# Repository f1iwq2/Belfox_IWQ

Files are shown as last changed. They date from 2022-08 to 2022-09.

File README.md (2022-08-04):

==============
Carte de remplacement pour portail coulissants BELFOX
pour pilotage de moteurs à courant continu - A base d'arduino nano

Documents dans le fichier pdf
Fichiers schéma Kicad
fichiers gerber dans le répertoire trace

Replacement control board for BELFOX sliding gates
Drive a DC moteur

Documents in pdf files
Kicad board schematics files
gerber files in trace directory

https://youtu.be/OYu1DCdmt-g

image::carte.jpg[]

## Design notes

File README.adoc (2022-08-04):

Carte BELFOX IWQ
================
Carte de remplacement pour portail coulissants BELFOX
pour pilotage de moteurs à courant continu - A base d'arduino nano

Documents dans le fichier pdf
Fichiers schéma Kicad
fichiers gerber dans le répertoire trace

Replacement control board for BELFOX sliding gates
Drive a DC moteur

Documents in pdf files
Kicad board schematics files
gerber files in trace directory

https://youtu.be/OYu1DCdmt-g

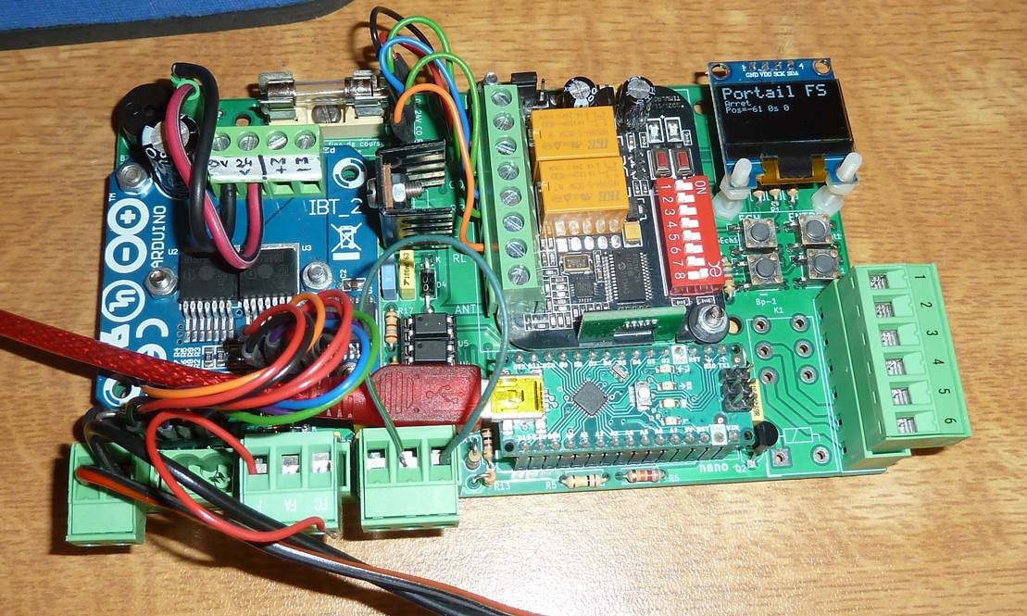
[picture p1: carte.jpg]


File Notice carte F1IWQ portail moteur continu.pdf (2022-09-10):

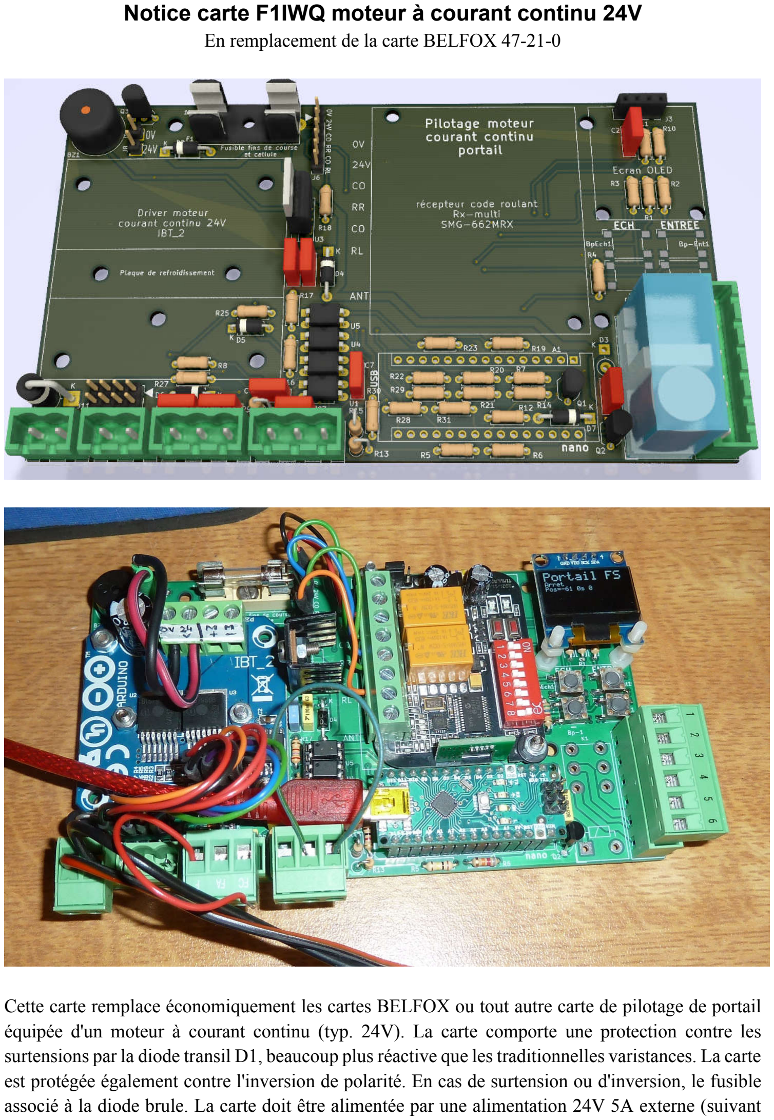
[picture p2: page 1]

### Notice carte F1IWQ moteur à courant continu 24V

En remplacement de la carte BELFOX 47-21-0

Cette carte remplace économiquement les cartes BELFOX ou tout autre carte de pilotage de portail équipée d'un moteur à courant continu (typ. 24V). La carte comporte une protection contre les surtensions par la diode transil D1, beaucoup plus réactive que les traditionnelles varistances. La carte est protégée également contre l'inversion de polarité. En cas de surtension ou d'inversion, le fusible associé à la diode brule. La carte doit être alimentée par une alimentation 24V 5A externe (suivant spécification du moteur). Par exemple la TXH 120-124 de tracopower (RS:706-6303). Prévoir un fusible en ligne de 5AF. Le module de pilotage du moteur est un IBT_2.

### Montage

Le boitier dans lequel la carte est montée n'autorise que les hauteurs de composants inférieures à 34 mm maximum. Le composant le plus haut est le relais (25mm)
Monter l'écran OLED sur le connecteur J3 et mettre deux vis / écrous M2,5 avec entretoise.
Monter le récepteur de télécommande avec des vis écrous M3 ; la platine du récepteur doit être surélevée d'un écrou. Mettre des rondelles nylon pour l'isolation au contact de la platine du récepteur. Insérer un fusible rapide 5x20 1A F sur le support.
Insérer l'Arduino NANO programmé à l'emplacement A1, prise USB vers la gauche sur 2 supports HE10 femelles 15 broches.

Le radiateur du module IBT_2 est à remplacer par deux barres aluminium 49x22mm ep 2mm superposées et percées de deux trous placés l'une sur l'autre. Elles doivent être enduites de graisse silicone à dissipation de chaleur en contact avec le module sauf sur la face en contact avec le module. Positionner une feuille d'interface thermique isolante 0,5 mm sur toute la surface du plat d'aluminium en contact avec le module pour éviter les courts-circuits

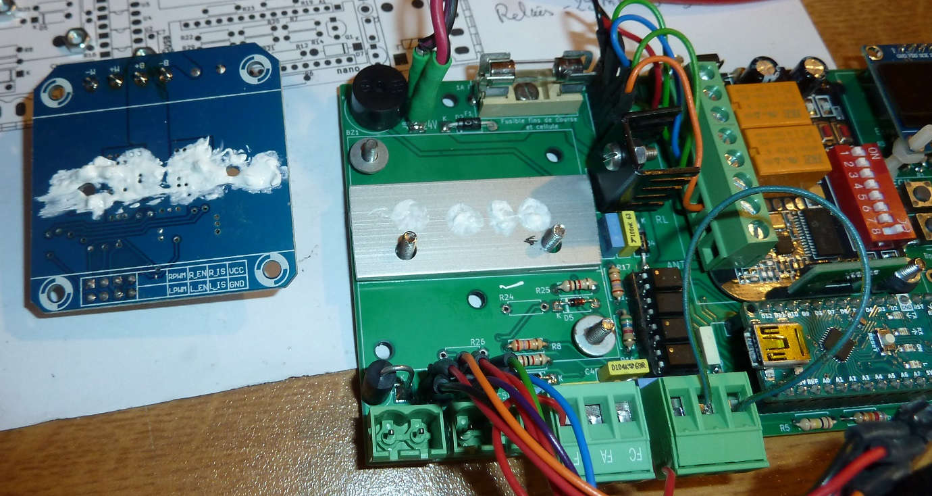
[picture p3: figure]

Pour le circuit V1.0 :
Les résistances R18, R24 et R26 ne doivent pas être montées
Le point haut de l'empreinte de la résistance R18 (points CO du bornier J6, marqué par une flèche rouge) doit être relié au 0V par un fil.

Pour le circuit V1.1 :
La diode D7 d'alimentation de l'Arduino est supprimée.

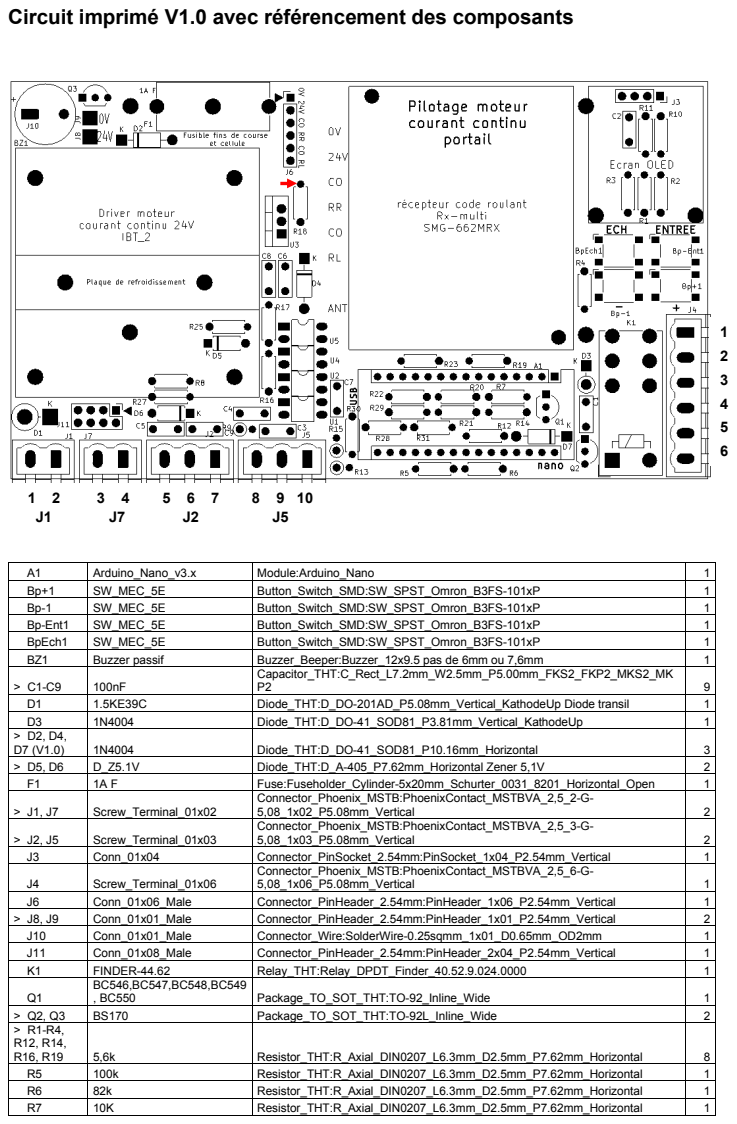
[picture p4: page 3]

Circuit imprimé V1.0 avec référencement des composants

A1 | Arduino_Nano_v3.x | Module:Arduino_Nano | 1
Bp+1 | SW_MEC_5E | Button_Switch_SMD:SW_SPST_Omron_B3FS-101xP | 1
Bp-1 | SW_MEC_5E | Button_Switch_SMD:SW_SPST_Omron_B3FS-101xP | 1
Bp-Ent1 | SW_MEC_5E | Button_Switch_SMD:SW_SPST_Omron_B3FS-101xP | 1
BpEch1 | SW_MEC_5E | Button_Switch_SMD:SW_SPST_Omron_B3FS-101xP | 1
BZ1 | Buzzer passif | Buzzer_Beeper:Buzzer_12x9.5 pas de 6mm ou 7,6mm | 1
> C1-C9 | 100nF | Capacitor_THT:C_Rect_L7.2mm_W2.5mm_P5.00mm_FKS2_FKP2_MKS2_MK P2 | 9

D1 | 1.5KE39C | Diode_THT:D_DO-201AD_P5.08mm_Vertical_KathodeUp Diode transil | 1
D3 | 1N4004 | Diode_THT:D_DO-41_SOD81_P3.81mm_Vertical_KathodeUp | 1
> D2, D4, D7 (V1.0) | 1N4004 | Diode_THT:D_DO-41_SOD81_P10.16mm_Horizontal | 3

> D5, D6 | D_Z5.1V | Diode_THT:D_A-405_P7.62mm_Horizontal Zener 5,1V | 2
F1 | 1A F | Fuse:Fuseholder_Cylinder-5x20mm_Schurter_0031_8201_Horizontal_Open | 1
> J1, J7 | Screw_Terminal_01x02 | Connector_Phoenix_MSTB:PhoenixContact_MSTBVA_2,5_2-G-5,08_1x02_P5.08mm_Vertical | 2

> J2, J5 | Screw_Terminal_01x03 | Connector_Phoenix_MSTB:PhoenixContact_MSTBVA_2,5_3-G-5,08_1x03_P5.08mm_Vertical | 2

J3 | Conn_01x04 | Connector_PinSocket_2.54mm:PinSocket_1x04_P2.54mm_Vertical | 1
J4 | Screw_Terminal_01x06 | Connector_Phoenix_MSTB:PhoenixContact_MSTBVA_2,5_6-G-5,08_1x06_P5.08mm_Vertical | 1

J6 | Conn_01x06_Male | Connector_PinHeader_2.54mm:PinHeader_1x06_P2.54mm_Vertical | 1
> J8, J9 | Conn_01x01_Male | Connector_PinHeader_2.54mm:PinHeader_1x01_P2.54mm_Vertical | 2
J10 | Conn_01x01_Male | Connector_Wire:SolderWire-0.25sqmm_1x01_D0.65mm_OD2mm | 1
J11 | Conn_01x08_Male | Connector_PinHeader_2.54mm:PinHeader_2x04_P2.54mm_Vertical | 1
K1 | FINDER-44.62 | Relay_THT:Relay_DPDT_Finder_40.52.9.024.0000 | 1
Q1 | BC546,BC547,BC548,BC549 , BC550 | Package_TO_SOT_THT:TO-92_Inline_Wide | 1

> Q2, Q3 | BS170 | Package_TO_SOT_THT:TO-92L_Inline_Wide | 2
> R1-R4, R12, R14, R16, R19 | 5,6k | Resistor_THT:R_Axial_DIN0207_L6.3mm_D2.5mm_P7.62mm_Horizontal | 8

R5 | 100k | Resistor_THT:R_Axial_DIN0207_L6.3mm_D2.5mm_P7.62mm_Horizontal | 1
R6 | 82k | Resistor_THT:R_Axial_DIN0207_L6.3mm_D2.5mm_P7.62mm_Horizontal | 1
R7 | 10K | Resistor_THT:R_Axial_DIN0207_L6.3mm_D2.5mm_P7.62mm_Horizontal | 1

> R8, R17 | 2,7k | Resistor_THT:R_Axial_DIN0207_L6.3mm_D2.5mm_P7.62mm_Horizontal | 2
> R9, R13, R15 | 2,7k | Resistor_THT:R_Axial_DIN0207_L6.3mm_D2.5mm_P2.54mm_Vertical | 3
> R10, R11 | 330 | Resistor_THT:R_Axial_DIN0207_L6.3mm_D2.5mm_P7.62mm_Horizontal | 2
> R19, R20-R31 | 1k | Resistor_THT:R_Axial_DIN0207_L6.3mm_D2.5mm_P7.62mm_Horizontal | 13
> U1, U2, U4, U5 | SFH617A-1 | Package_DIP:DIP-4_W7.62mm_LongPads | 4
U3 | LM7805_TO220 | Package_TO_SOT_THT:TO-220-3_Vertical + radiateur | 1

Connecteurs Phoenix contact:
Ces connecteurs sont composés d'une partie mâle à souder et d'une partie femelle à bornier constituant deux références de commande séparées :
connecteur mâle | connecteur femelle
Nb | | | à souder | | à vis
pts | Rep | Type | Ref Phoenix | Ref RS | Ref Phoenix | Ref RS
2 | J1,J7 | MSTBVA 2,5/2-G-5,08 | 17 55 73 6 | 189-6199 | 17 57 01 9 | 189-6010
3 | J2-J5 | MSTBVA 2,5/3-G-5,08 | 17 55 74 9 | 189-6212 | 17 57 02 2 | 189-6026
6 | J4 | MSTBVA 2,5/6-G-5,08 | 17 55 77 8 | 189-6240 | 17 57 05 1 | 189-6054

Feuille thermique pour isolation électrique et conduction thermique du module IBT_2 :
RS | | 707-4590
Conrad | | 189048 ; 954400001
Il existe beaucoup de fabricants de médias thermiques.

Le régulateur U3 doit absolument être monté sur un radiateur.

Le relais K1, a pour fabricant finder et pour référence 40.52.9.024.0000. C'est un relais deux voies C+NO+NC, bobine 24V.

A1 est un Arduino NANO, il peut être un clone chinois.

U1, U2, U4 et U5 sont 4 optocoupleurs SFH617A ou un LTV847. A monter sur support dip-16 en cas de remplacement d'un optocoupleur défaillant.

Le module OLED est un 0,96" 128x64

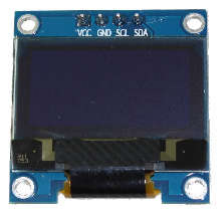
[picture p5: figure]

Le récepteur radio est un module Rx-multi SMG-662MRX débarrassé de son boitier. Il doit être surélevé de l'épaisseurs des picots côté soudures par l'épaisseur d'un écrou.

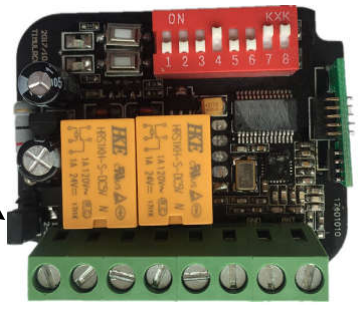
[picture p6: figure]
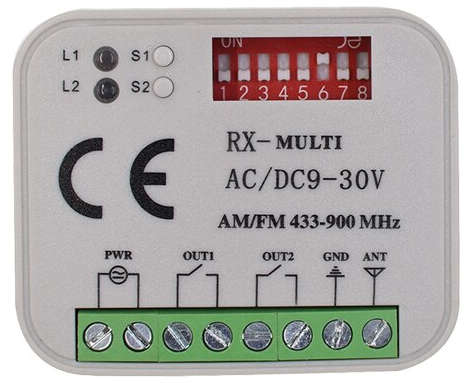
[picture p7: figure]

C'est un récepteur multi normes multi fréquences, à code roulant ou fixe. Il faut positionner le strap sur la position 2-3 (alimentation 24V-30V)

Module IBT_2 est le driver du moteur à courant continu, débarrassé de son radiateur :

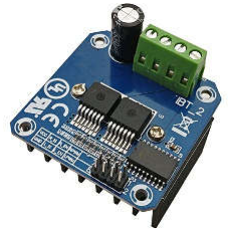
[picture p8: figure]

Attention, certains modules IBT_2 défectueux ne délivrent pas le courant moteur sur les bornes R_IS et/ou L_IS. Ces sorties sont à tester ! On peut retourner le bornier de puissance vert pour faciliter le branchement des 4 fils.

Strap en
position
2-3

### Description des borniers

Borniers avant (J1 J7 J2 J5)
1 | Entrée 24V 5A venant de l'alimentation, elle doit être protégée par un fusible externe de 5A.
2 | 0V de l'alimentation 24V
3 | Alimentation 24V de la cellule du portail via fusible F1
4 | 0V de l'alimentation de la cellule
5 | Alimentation 24V des fins de course via fusible F1
6 | Entrée 24V contact du fin de course "fermé"
7 | Entrée 24V contact du fin de course "ouvert"
8 | Entrée 24V commande de manœuvre du portail
9 | Entrée 24V contact de la cellule
10 | 24V commun de la cellule et de la commande de manœuvre via fusible F1

Bornier latéral J4
1 | Contact NO1
2 | Commun 1
3 | Contact NC1
4 | Contact NO2
5 | Commun 2
6 | Contact NC2

Le bornier J4 est relié au relais K1 qui colle pendant le fonctionnement du portail + temporisation de 10s. Il sert à alimenter l'éclairage et la signalisation clignotante.

Bornier J6 vers récepteur Rx-multi | Bornier J11 vers module IBT_2
1 | 0V | 1 | RPWM
2 | 24V | 2 | LPWM
3 | 5V tamponné | 3 | REN
4 | Relais 1 Rx multi (RadioR) | 4 | LEN
5 | 5V tamponné | 5 | RIS
6 | Relais 2 Rx multi (RadioL) | 6 | LIS
| | 7 | 5V
| | 8 | 0V
Bornier J3 écran OLED
1 | SDA | J8 | 24V alimentation IBT_2
2 | SCL | | (cosse faston 3mm)
3 | 5V | J9 | 0V alimentation IBT_2
4 | 0V | | (cosse faston 3mm)

L'antenne est à raccorder directement sur le module récepteur (ANT)

### Câblage

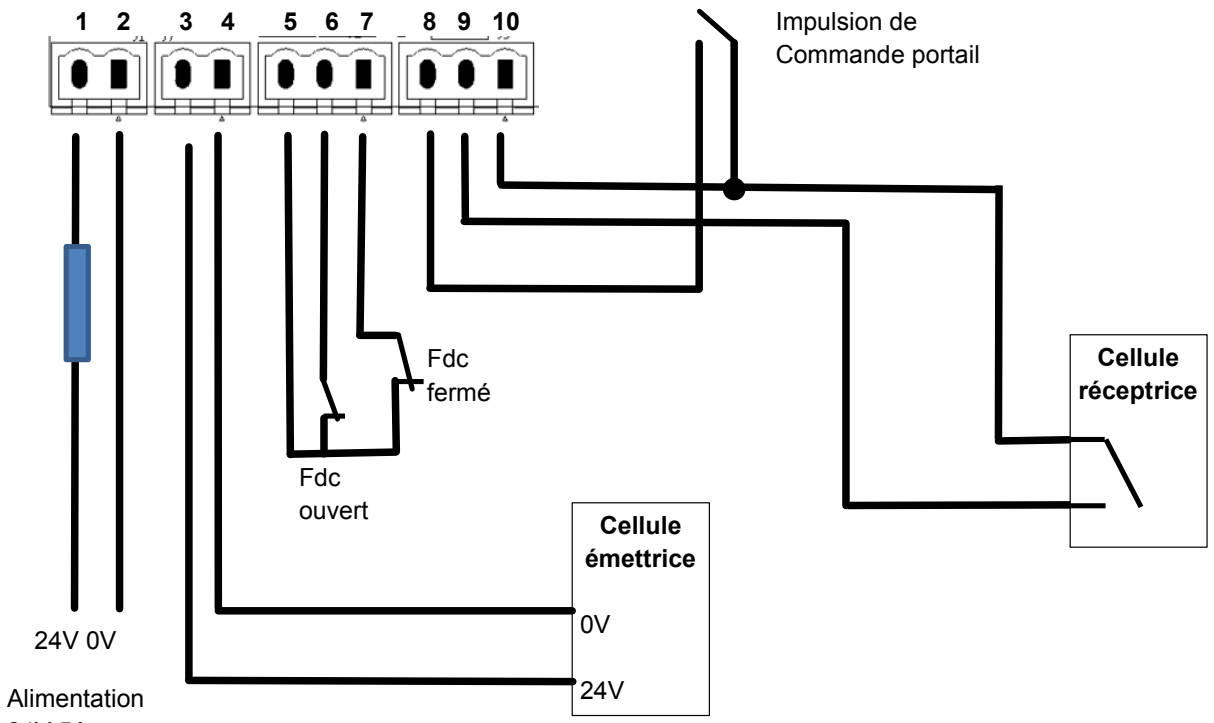
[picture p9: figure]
Cellule émettrice; Cellule réceptrice; Fdc fermé; Fdc ouvert; Impulsion de Commande portail; Alimentation

Bornier J4

Important : Les fins de course "ouvert" et "fermé" ne doivent pas être inversés l'un l'autre. Ils doivent être de type NC (ouverture enclenchés)

24V 5A

1
2
3
4
5
6

Projecteur

Lampe avertissement

Alimentation

Alimentation

### Note sur les fins de course (Fdc)

Les fins de course peuvent être :

### 1. ILS diamètre M8 de type reed 2 fils non polarisé (ILS) :

Celduc | PTI40020 | (Farnell 2251795) !détection NO!
LittleFuse | 59070-4-S-02-A | (Farnell 5540884) détection NC
Ils nécessitent un aimant pour la détection.

### 2. Détecteurs inductifs 2 ou 3 fils polarisés ou non :

Le connecteur "5" délivre du 24V direct après fusible F1 de 1A ce qui permet d'utiliser des détecteurs inductifs industriels. Plus le diamètre est gros et plus la portée est importante.
XS508B1DBL2 (Farnell 3113445) 2 fils diamètre M8 portée 1,5 mm contact NC

Les détecteurs inductifs nécessitent un "drapeau" métallique pour la détection.
On peut mettre des détecteurs 3 fils (24V, 0V, signal) pour augmenter la portée de 4 à 6 mm.
3. Fins de course mécaniques.

Ils nécessitent un drapeau quelconque pour la détection. Utiliser le contact NC. Exemple : XCKN118P20

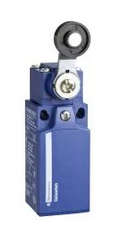
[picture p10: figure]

La programmation des télécommandes s'effectue sur le module RX-multi.

### Liste des écrans

Menu

L'entrée dans le menu pour le paramétrage se fait en appuyant sur le bouton ENTREE pendant 1 seconde.

Ecran 1

L'écran menu affiche des paramètres modifiables ou non ainsi que des commandes :

Apprentissage
Sens d'ouverture=x
Sequencement=x
Sauvegarde EPROM
Gestion telecomm
Affichage entrees
Tps max fonction:xx
Tps accel
Tps decel
Dist decel

Pour changer de ligne appuyer sur + ou -. Pour choisir une ligne appuyer sur ENTREE
Pour sortie appuyer sur ECH

L'origine de la mesure est fixée sur le fin de course ouvert (portail ouvert). Tant que cette position n'a pas été reconnue et que les fdc ouvert et fermé n'ont pas été actionnés par le portail par un trajet en continu au moins une fois, le portail se déplacera en petite vitesse (PV).

Apprentissage :
L'entrée en apprentissage n'est autorisé que si la cellule est ok, le fusible F1 et que les deux fins de course ne soient pas enclenchés simultanément.
Effectue deux allers-retours du portail pour fixer l'origine du portail et les positions de ralentissement avant fermeture et après ouverture ; puis mémorise les courants maximums du moteur ; il mémorise les paramètres de position du Fdc ferme et le courant maximal dans l'eeprom.
Sens d'ouverture 0 ou 1 : 0=ouverture à gauche 1=ouverture à droite
Séquencement 0 ou 1 : 0=pas à pas (ouverture fermeture sans arrêt) 1=séquentielle (ouverture arrêt fermeture arrêt)
Sauvegarde EPROM : écrit les paramètres modifiés dans l'EPROM pour la sauvegarde Affichage des entrées : affiche les entrées en dynamique (fin de course et boutons)
Tps max fonction: Temps maximal de fonctionnement en secondes au-delà duquel le portail s'arrête.
Tps accel/decel : Temps de d'accélération et de décélération en dixièmes de secondes.
Dist decel : Distance du fin de course avant laquelle le portail passe de GV en PV.

**MENU**
>Apprentissage
Sens d'ouverture=0
Sequencement=1
Sauvegarde EPROM
Affichage entrees
Tps max fonction:99
Tps_accel=10

Mode exploitation

En mode exploitation (hors mode menu) si on appuie sur une télécommande, l'écran affiche les informations suivantes :

La position calculée du portail est affichée (5465).
Si un mouvement est en cours, le temps en secondes de la durée du mouvement est affiché (ici 15s). 208 indique l'image instantanée du courant moteur en points analogiques.
Si la durée de mouvement est supérieure au temps maximal de fonctionnement, le mouvement s'arrête sur un message d'erreur.
L'intensité MAX affichée correspond à la valeur maximale de l'intensité moteur relevée en apprentissage majorée de 10%.
Commande radio indique que la manœuvre a été provoquée par la télécommande.
Commande bornier indique que la manœuvre a été provoquée par la fermeture du contact entre 8 et 10.
Si la cellule est occultée (entrée 2 sur bornier J5), un message s'affiche et le portail ne pourra pas être manœuvré.

Un appui sur la touche "+" avance le portail
Un appui sur la touche "‒" recule le portail
Un appui sur la touche "ECH" arrête le portail

En cours d'avancée si un obstacle survient, le portail recule en petite vitesse.
En cours de recul, si un obstacle survient, le portail s'arrête.

La carte peut gérer les télécommandes à deux boutons mais elles sont gérées de la même façon. Dans la programmation du code, on pourrait associer un bouton pour l'ouverture et un bouton pour la fermeture.

## PORTAIL IWQ

Recul
Pos=5465 15s 208

Commande radio

Intensite MAX=973

Mesure de l'intensité moteur

Elle est mesurée en régime établi (hors pentes d'accélération et de décélération et après stabilisation d'une seconde). La formule approchée entre la vitesse demandée (consigne) et l'intensité est:

=
×

Imax : Intensité mesurée pendant l'apprentissage. Elle est mesurée à vitesse maxi (consigne=255). Consigne : consigne de vitesse de 0 à 255.

Exemple pour une vitesse de consigne de 150, et une intensité Imax mesurée à 843,
I = 1433. Si on dépasse cette valeur +10% en mesure de courant à la vitesse de 150, le moteur est en surintensité et on considère qu'on détecte un obstacle. L'intensité est plus grande à basse vitesse qu'à haute vitesse. Ceci est programmé par la ligne suivante :

if (intensite>255L*intensite_max/consigne)

Cette valeur de seuil permet de détecter un obstacle.

### Erreurs pouvant être affichées

- Courant moteur élevé
Indique que le courant dans le moteur dépassé le maximal autorisé. Cette erreur arrête le portail si celui-ci est en mouvement de recul, et recule le portail si celui-ci est en mouvement d'avance
Le buzzer bipe 1 ou 2 fois tous les 8 secondes pendant 1 heure.
1 bip : erreur courant durant la fermeture
2 bips : erreur courant durant l'ouverture.
- Erreur mvt trop long
Indique que le temps maximum de fonctionnement a été atteint. Cette erreur arrête le portail. Le buzzer bipe 3 fois tous les 8 secondes pendant 1 heure.

-Fusible F1 HS
Indique que le fusible F1 sur la carte est HS. Cette erreur immobilise le portail. Le buzzer bipe 4 fois tous les 8 secondes pendant 1 heure.

-Cellule occultée
Indique que la cellule est occultée. Le portail ne peut se fermer.

### Prix €

Module IBT_2 | 12
Module OLED | 6
Récepteur universel | 42
Platine | 7
Arduino nano | 22
Composants | 39
Total | 128

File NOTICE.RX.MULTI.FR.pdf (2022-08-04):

NOTICE D’UTILISATION

RECEPTEUR MULTI-MARQUES / MULTI-FREQUENCES 433MHz – 868MHZ

1/ Schéma électrique du récepteur

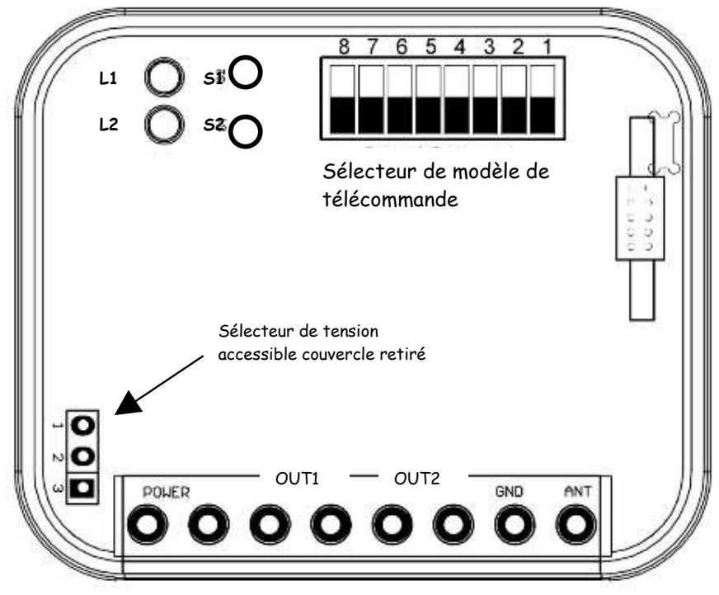
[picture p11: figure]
Sélecteur de tension accessible couvercle retiré; Sélecteur de modèle de télécommande; OUT1; OUT2

S1 | Bouton d’enregistrement associé à la sortie OUT1
S2 | Bouton d’enregistrement associé à la sortie OUT2
POWER | Alimentation de 9V à 30V AC ou DC. Si la tension est < 24V, laisser le réglage d’usine Si la tension est > 24V enlerver le couvercle (2 vis à l’arrière) et insérer le cavalier du sélecteur de tension sur les bornes 1-2
OUT1 | Sortie « homme présent » à contact N.O - 1A/120Vac ou 1A/24Vdc.
OUT2 | Sortie « homme présent » à contact N.O - 1A/120Vac ou 1A/24Vdc.
GND | Tresse de masse de l’antenne
ANT | Ame de l’antenne ou antenne spiralée fournie

2/ Sélection du modèle de télécommande

A l’aide du tableau 1, sélectionner le modèle de la télécommande utilisée et mettre les interrupteurs 1 à 8 dans la position indiquée. Si votre télécommande n’est pas dans la liste, sélectionner le modèle le plus proche.

3/ Enregistrement d’une télécommande

- Mettre le récepteur sous tension. Les voyants L1 et L2 s’allument pendant un bref instant.
- Donner une impulsion sur le bouton S de la sortie OUT que l’on souhaite programmer. Le voyant L correspondant s’allume fixe.
- Prendre la télécommande et appuyer sur le bouton que l’on souhaite enregistrer : Si le voyant L se met à clignoter alors le code est compatible. Maintenir l’appui jusqu’à ce que le voyant L s’allume fixe. Cette opération peut durer plusieurs secondes. La fermeture du contact OUT se fait entendre. Relâcher le bouton de la télécommande.
Si le voyant L reste allumé fixe alors le code de la télécommande n’est pas compatible avec la sélection des interrupteurs 1 à 8.
- Les sorties OUT1 et OUT2 fonctionnent en mode « homme présent ». Le contact reste fermé tant que le bouton de la télécommande enregistrée est enfoncé.
- Répéter les opérations 2/ et 3/ pour toute nouvelle télécommande. La capacité d’enregistrement est de 250 télécommandes.

4/ Effacement des télécommandes

- Appuyer sur l’un des bouton S. Le voyant L correspondant s’allume.
- Maintenir l’appui sur S jusqu’à ce que le voyant L s’éteigne.
- Relâcher le bouton S. Les 2 voyants L1 et L2 s’allument brièvement indiquant l’effacement de la mémoire.

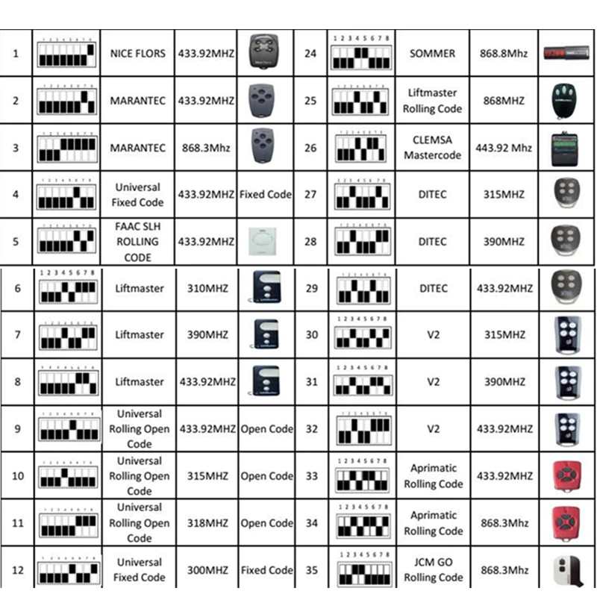
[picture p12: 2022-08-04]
codes-1-12.jpg

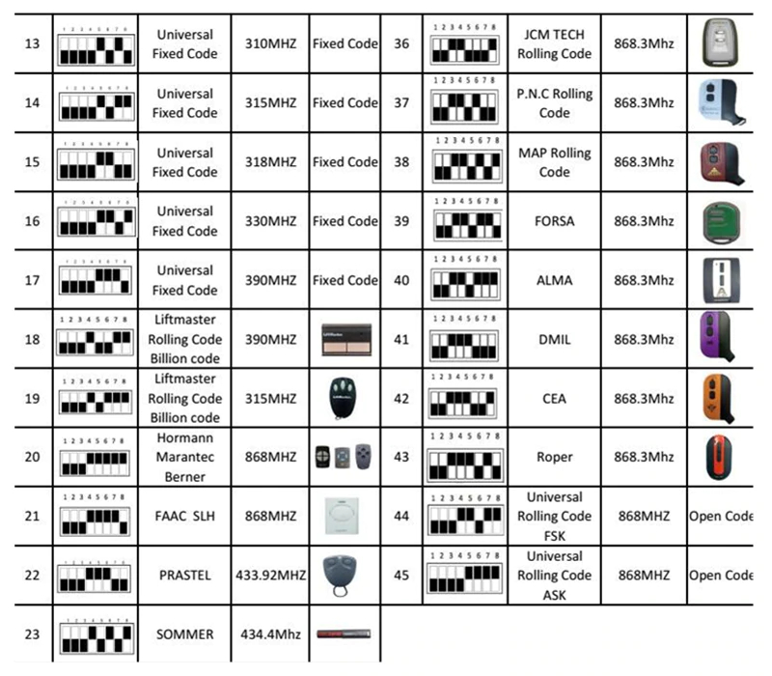
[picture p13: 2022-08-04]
codes-13-23.jpg

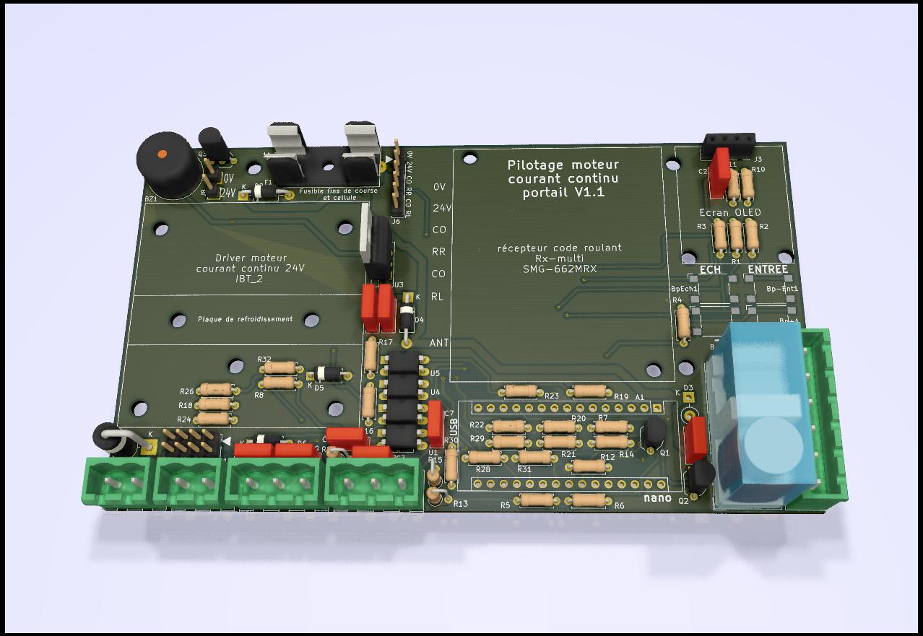
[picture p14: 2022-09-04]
portail_moteur_continu.jpg

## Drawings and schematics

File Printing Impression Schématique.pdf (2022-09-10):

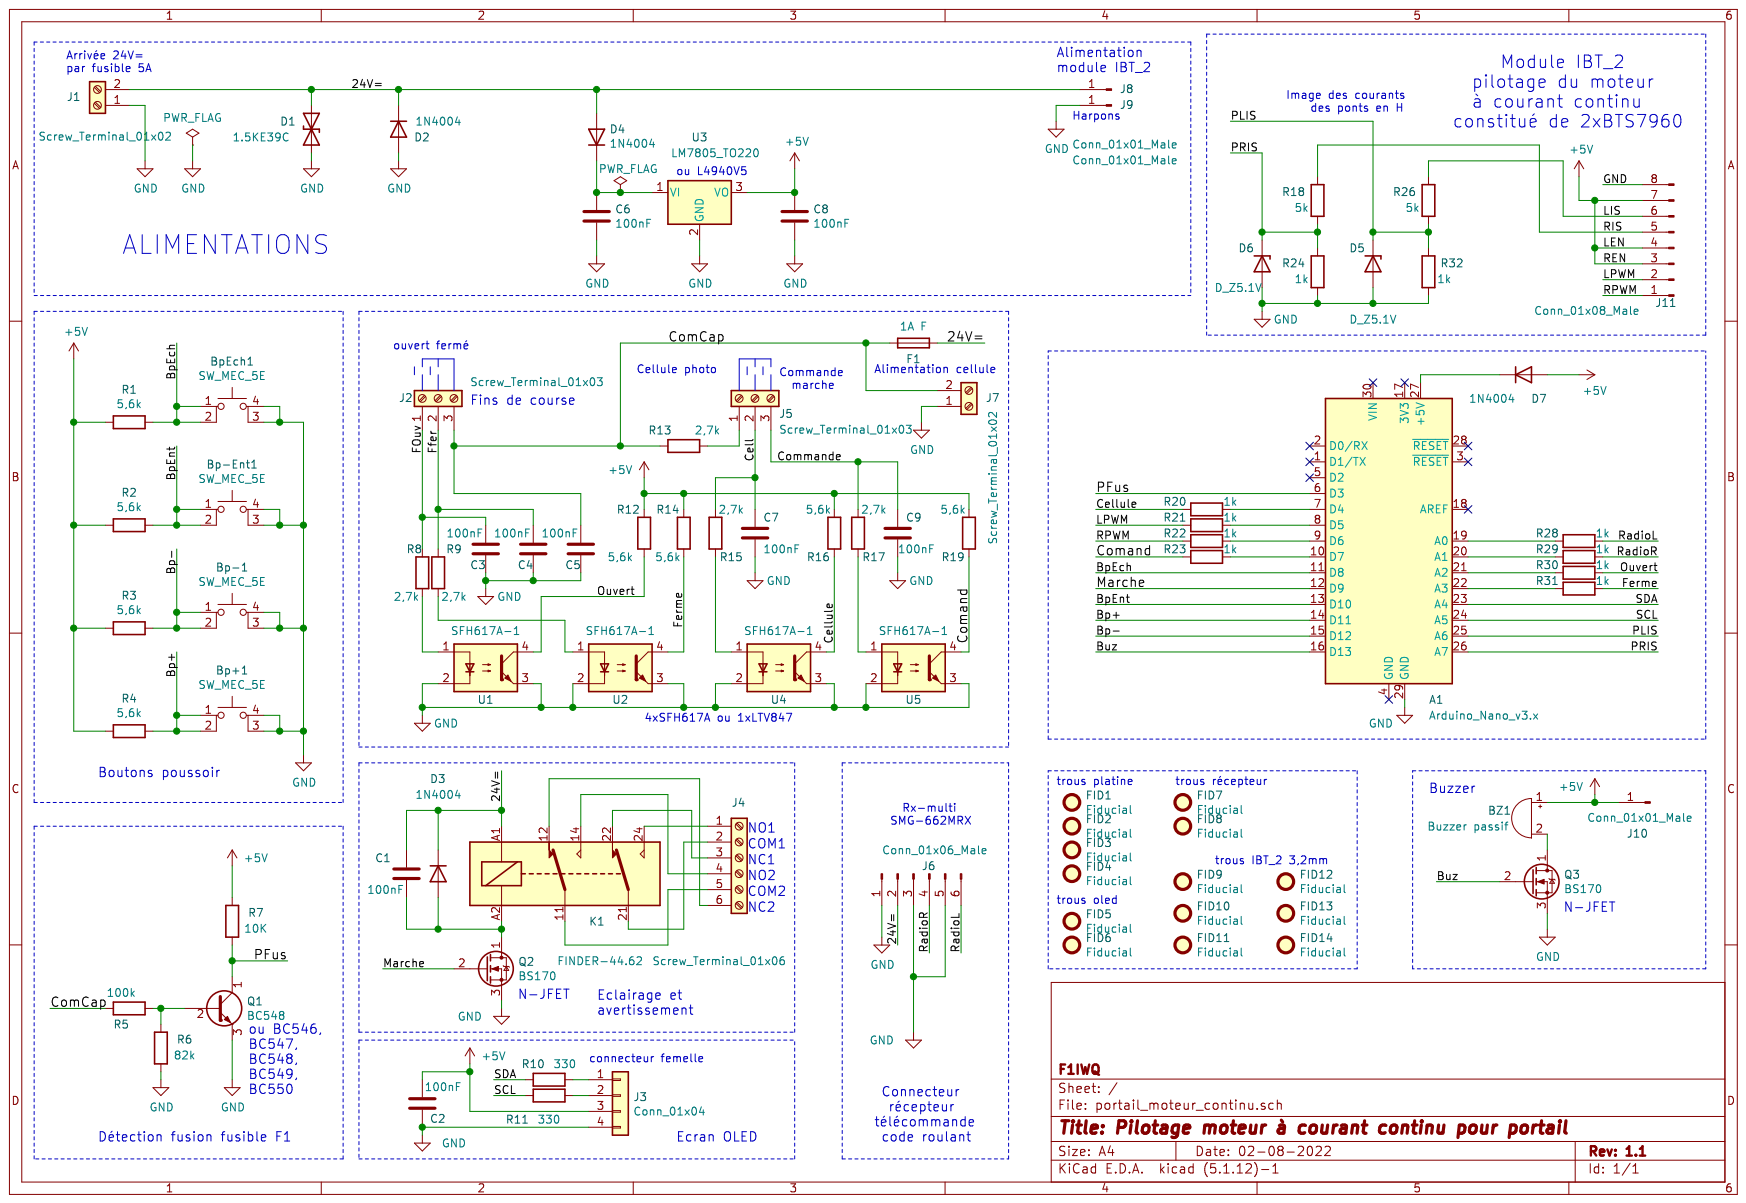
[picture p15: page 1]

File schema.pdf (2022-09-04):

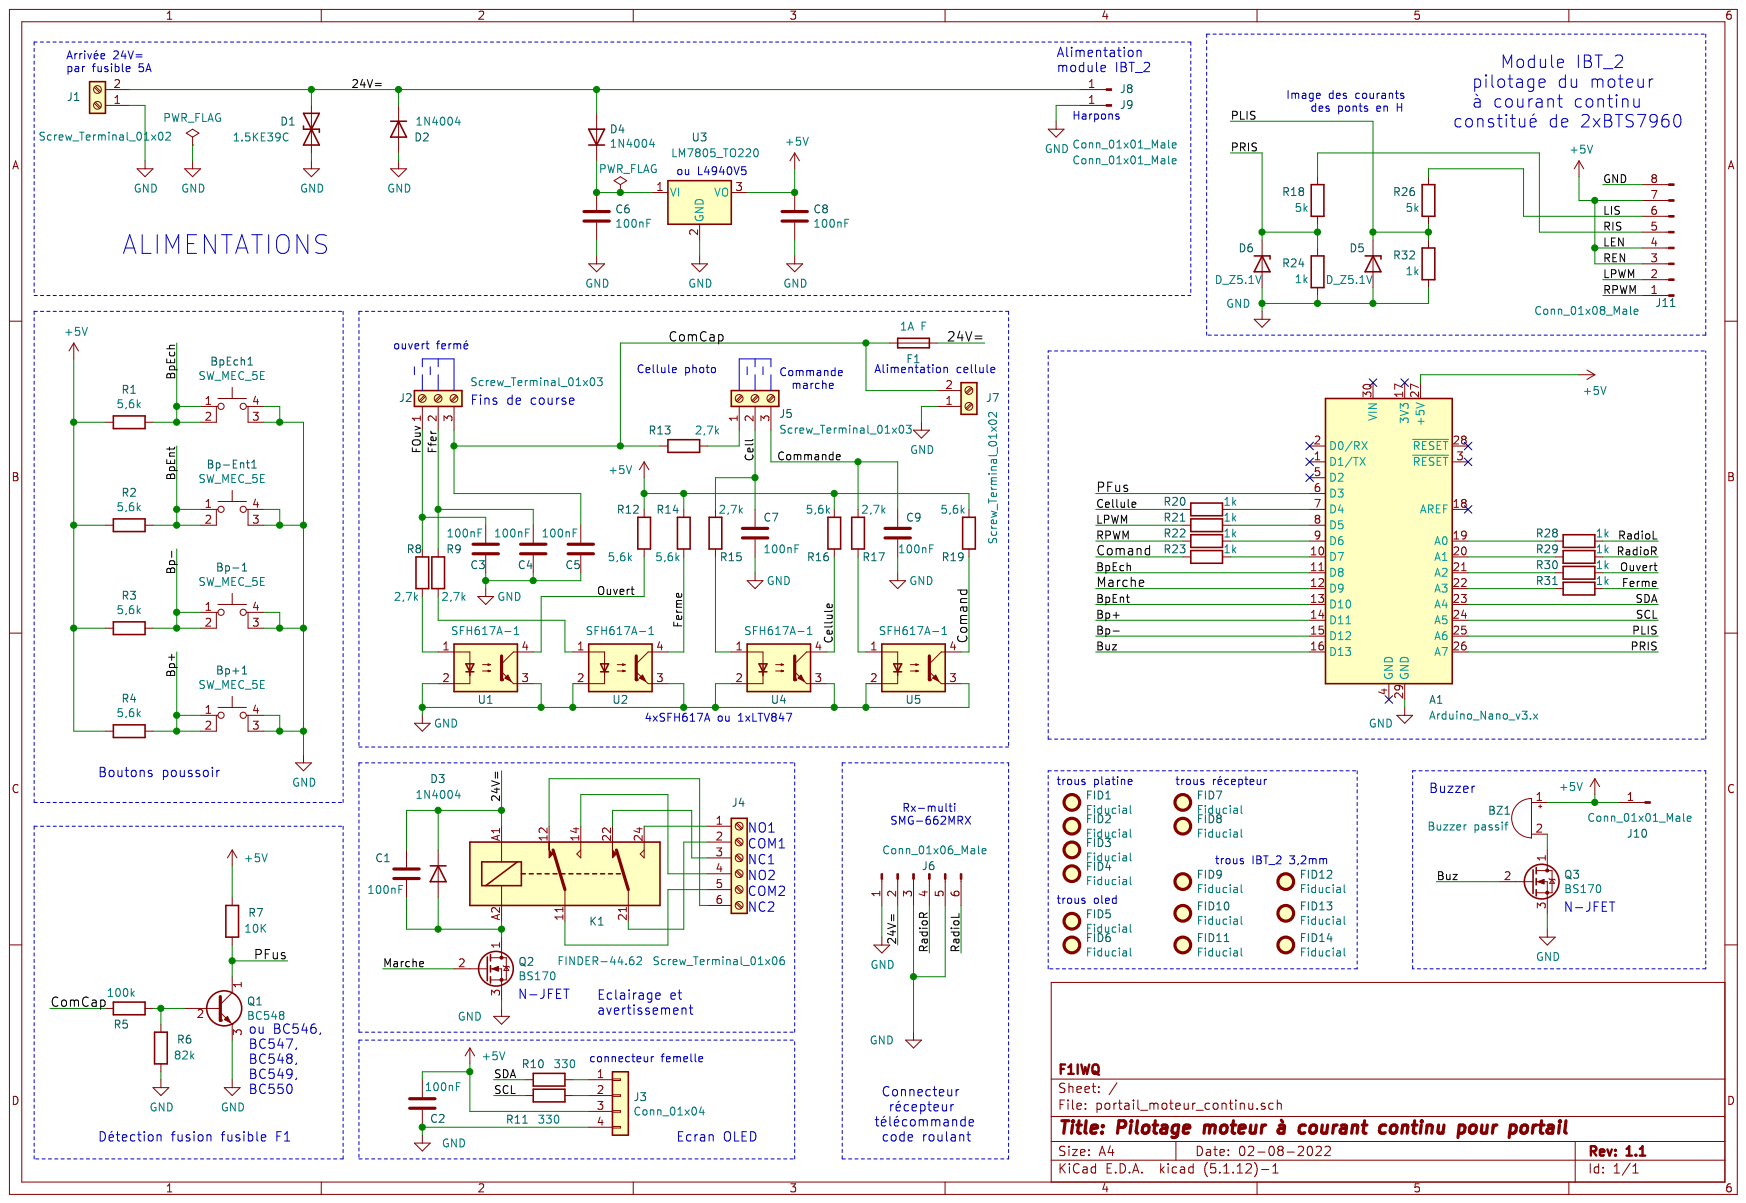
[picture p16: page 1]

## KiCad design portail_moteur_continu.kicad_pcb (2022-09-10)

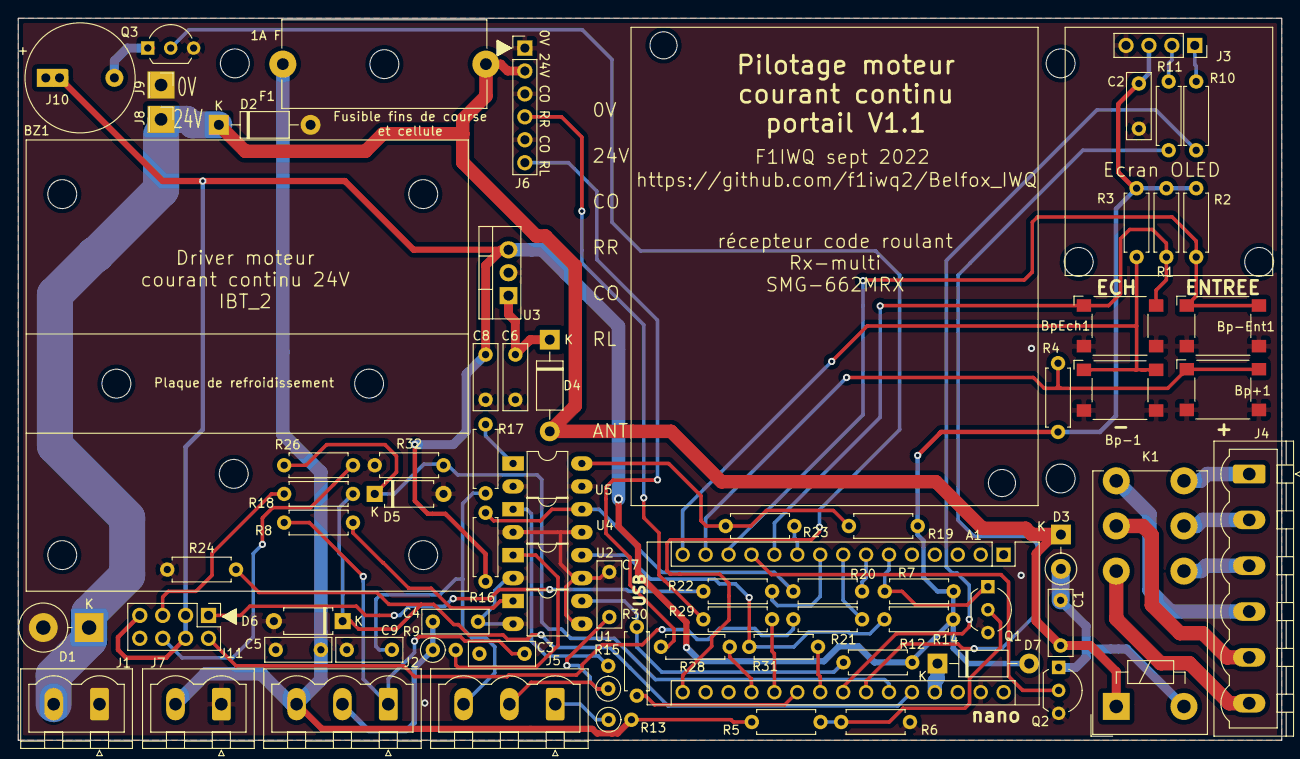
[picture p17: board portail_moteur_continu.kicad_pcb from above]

Board: 2 copper layers, 140.0 x 80.0 mm, 87 parts (0 on the bottom side), 55 nets.

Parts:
A1: Arduino_Nano_v3.x; Arduino_Nano
BZ1: Buzzer passif; Buzzer_12x9.5RM7.6
Bp+1: SW_MEC_5E; SW_SPST_Omron_B3FS-101xP
Bp-1: SW_MEC_5E; SW_SPST_Omron_B3FS-101xP
Bp-Ent1: SW_MEC_5E; SW_SPST_Omron_B3FS-101xP
BpEch1: SW_MEC_5E; SW_SPST_Omron_B3FS-101xP
C1, C2, C3, C4, C5, C6, C7, C8, C9: 100nF; C_Rect_L7.2mm_W2.5mm_P5.00mm_FKS2_FKP2_MKS2_MKP2
D1: 1.5KE39C; D_DO-201AD_P5.08mm_Vertical_KathodeUp
D2, D4, D7: 1N4004; D_DO-41_SOD81_P10.16mm_Horizontal
D3: 1N4004; D_DO-41_SOD81_P3.81mm_Vertical_KathodeUp
D5, D6: D_Z5.1V; D_A-405_P7.62mm_Horizontal
F1: 1A F; Fuseholder_Cylinder-5x20mm_Schurter_0031_8201_Horizontal_Op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
FID1, FID2, FID3, FID4, FID5, FID6, FID9, FID10, FID11, FID12, FID13, FID14: Fiducial; MountingHole_3.2mm_M3
FID7, FID8: Fiducial; MountingHole_3mm
J1, J7: Screw_Terminal_01x02; PhoenixContact_MSTBVA_2,5_2-G-5,08_1x02_P5.08mm_Vertical
J2, J5: Screw_Terminal_01x03; PhoenixContact_MSTBVA_2,5_3-G-5,08_1x03_P5.08mm_Vertical
J3: Conn_01x04; PinSocket_1x04_P2.54mm_Vertical
J4: Screw_Terminal_01x06; PhoenixContact_MSTBVA_2,5_6-G-5,08_1x06_P5.08mm_Vertical
J6: Conn_01x06_Male; PinHeader_1x06_P2.54mm_Vertical
J8, J9: Conn_01x01_Male; PinHeader_1x01_P2.54mm_Vertical
J10: Conn_01x01_Male; SolderWire-0.25sqmm_1x01_D0.65mm_OD2mm
J11: Conn_01x08_Male; PinHeader_2x04_P2.54mm_Vertical
K1: FINDER-44.62; Relay_DPDT_Finder_40.52
Q1: BC548; TO-92_Inline_Wide
Q2, Q3: BS170; TO-92L_Inline_Wide
R1, R2, R3, R4, R12, R14, R16, R19: 5,6k; R_Axial_DIN0207_L6.3mm_D2.5mm_P7.62mm_Horizontal
R5: 100k; R_Axial_DIN0207_L6.3mm_D2.5mm_P7.62mm_Horizontal
R6: 82k; R_Axial_DIN0207_L6.3mm_D2.5mm_P7.62mm_Horizontal
R7: 10K; R_Axial_DIN0207_L6.3mm_D2.5mm_P7.62mm_Horizontal
R8, R17: 2,7k; R_Axial_DIN0207_L6.3mm_D2.5mm_P7.62mm_Horizontal
R9, R13, R15: 2,7k; R_Axial_DIN0207_L6.3mm_D2.5mm_P2.54mm_Vertical
R10, R11: 330; R_Axial_DIN0207_L6.3mm_D2.5mm_P7.62mm_Horizontal
R18, R26: 5k; R_Axial_DIN0207_L6.3mm_D2.5mm_P7.62mm_Horizontal
R20, R21, R22, R23, R24, R28, R29, R30, R31, R32: 1k; R_Axial_DIN0207_L6.3mm_D2.5mm_P7.62mm_Horizontal
U1, U2, U4, U5: SFH617A-1; DIP-4_W7.62mm_LongPads
U3: LM7805_TO220; TO-220-3_Vertical

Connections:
+5V: BZ1.1, C2.2, C8.1, D7.2, J3.3, J10.1, J11.3, J11.4, J11.7, R1.2, R2.2, R3.2, R4.2, R7.2, R12.1, R14.1, R16.1, R19.1, U3.3
/24V=: C1.1, D1.1, D2.1, D3.1, D4.2, F1.1, J1.2, J6.2, J8.1, K1.A1
/Bp+: A1.14, Bp+1.1, Bp+1.2, R4.1
/Bp-: A1.15, Bp-1.1, Bp-1.2, R3.1
/BpEch: A1.11, BpEch1.1, BpEch1.2, R1.1
/BpEnt: A1.13, Bp-Ent1.1, Bp-Ent1.2, R2.1
/Buz: A1.16, Q3.2
/Cell: C7.1, J5.2, R15.1
/Cellule: R16.2, R20.2, U4.4
/ComCap: C5.1, F1.2, J2.3, J7.2, R5.2, R13.2
/Comand: R19.2, R23.2, U5.4
/Commande: C9.1, J5.3, R17.1
/FOuv: C3.1, J2.1, R8.1
/Ferme: R14.2, R31.1, U2.4
/Ffer: C4.1, J2.2, R9.1
/LIS: J11.6, R26.2
/LPWM: J11.2, R21.2
/Marche: A1.12, Q2.2
/Ouvert: R12.2, R30.1, U1.4
/PFus: A1.6, Q1.1, R7.1
/PLIS: A1.25, D5.1, R26.1, R32.2
/PRIS: A1.26, D6.1, R18.1, R24.2
/RIS: J11.5, R18.2
/RPWM: J11.1, R22.2
/RadioL: J6.6, R28.1
/RadioR: J6.4, R29.1
/SCL: A1.24, R11.2
/SDA: A1.23, R10.2
GND: A1.29, Bp+1.3, Bp+1.4, Bp-1.3, Bp-1.4, Bp-Ent1.3, Bp-Ent1.4, BpEch1.3, BpEch1.4, C2.1, C3.2, C4.2, C5.2, C6.2, C7.2, C8.2, C9.2, D1.2, D2.2, D5.2, D6.2, J1.1, J3.4, J6.1, J6.3, J6.5, J7.1, J9.1, J11.8, Q1.3, Q2.3, Q3.3, R6.1, R24.1, R32.1, U1.2, U1.3, U2.2, U2.3, U3.2, U4.2, U4.3, U5.2, U5.3
unnamed: A1.7, R20.1
unnamed: A1.8, R21.1
unnamed: A1.9, R22.1
unnamed: A1.10, R23.1
unnamed: A1.19, R28.2
unnamed: A1.20, R29.2
unnamed: A1.21, R30.2
unnamed: A1.22, R31.2
unnamed: A1.27, D7.1
unnamed: BZ1.2, Q3.1
unnamed: C1.2, D3.2, K1.A2, Q2.1
unnamed: C6.1, D4.1, U3.1
unnamed: J3.1, R10.1
unnamed: J3.2, R11.1
unnamed: J4.1, K1.24
unnamed: J4.2, K1.21
unnamed: J4.3, K1.22
unnamed: J4.4, K1.14
unnamed: J4.5, K1.11
unnamed: J4.6, K1.12
unnamed: J5.1, R13.1
unnamed: Q1.2, R5.1, R6.2
unnamed: R8.2, U1.1
unnamed: R9.2, U2.1
unnamed: R15.2, U4.1
unnamed: R17.2, U5.1

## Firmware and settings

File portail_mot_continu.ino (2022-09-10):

// *********************************************************
// Version 07 09 2022 17h20
// Pilotage PWM de moteurs à courant continu
// pour ARDUINO NANO - F1IWQ
// pour la compilation et le téléchargement, sélectionner arduino NANO sinon le téléchargement ne fonctionnera pas.
// La fréquence PWM est par défaut de 976,56 Hz. Elle utilise les broches D5 et D6 et le pilotage PWM utilise le timer 0.
// Attention la fonction delay() utilise le timer 0 !
// Ne pas utiliser Tempo() dans la fonction traitement() ni dans les fonctions à l'intérieur à savoir recul() et avance() mais delay.
// pos fin=7300
// *********************************************************

// 1 tour programme principal (main) dure en moyenne 800 à 850µs

#include <TimerOne.h>
#include <EEPROM.h>

// bibliothèque ssd1306ascii allégée pour nano pour écran oled
#include <SSD1306Ascii.h>
#include <SSD1306AsciiAvrI2c.h>
#include <SSD1306AsciiSoftSpi.h>
#include <SSD1306AsciiSpi.h>
#include <SSD1306AsciiWire.h>
#include <SSD1306init.h>

// écran oled
#define I2C_ADDRESS 0x3C  // a changer suivant écran
// Sans broche RESET
#define RST_PIN -1

// organisation des lignes de l'écran d'exploitation---------------------
#define ligne_pos        3
#define ligne_erreur     7

#define Tempo_sortie_menu 30 // 30 s
// organisation des lignes Y de l'écran MENU (1)
#define premiere_ligneM  1
#define derniere_ligneM  9
#define offset_M         2  // début de l'affichage en Y=2

#define ligne_aprentiss  1  // lancement de l'apprentissage
#define ligne_Param_sens 2  // sens d'ouverture du portail
#define ligne_Param_PPS  3  // paramètre F7  : 0=ouverture complète/fermeture complète  1=ouverture/arret/fermeture/arret
#define ligne_eprom      4  // Sauvegarde des paramètres en EPROM
#define ligne_ES         5  // affichage des E/S
#define ligne_tpsmax     6  // temps maxi de fonctionnement
#define ligne_acc        7  // 
#define ligne_dec        8  // 
#define ligne_dist_dec   9  // distance de décélération au fins de courses


const String ligne_menu_S[]={"Apprentissage",
                             "Sens d'ouverture=",
                             "Sequencement=",
                             "Sauvegarde EPROM",
                             "Affichage entrees",
                             "Tps max fonction=",
                             "Tps accel=",
                             "Tps decel=",
                             "Dist decel="};


// ports d'entrées / sorties nano----------------------------------------
#define   buzzer     13     // D13 portB.5 led intégrée et buzzer
#define   BpM        12     // D12 portB.4 Bouton -
#define   BpP        11     // D11 portB.3 Bouton +
#define   BpE        10     // D10 portB.2 Bouton ENTREE
#define   infomarche  9     // D9  portB.1 Relais K1
#define   BpEch       8     // D8  portB.0 Bouton Ech
#define   Commande    7     // D7  portD.7 Commande ouverture/fermeture 
#define   RPWM        6     // D6  portD.6 pilotage PWM R
#define   LPWM        5     // D5  portD.5 pilotage PWM L
#define   Cellule     4     // D4  portD.4 Photo-cellule
#define   Fuse        3     // D3  portD.3 Fusible F1
#define   rien        2     // D2  portD.2 

// port C de l'ATMEGA328 
#define   Scl        A5     // portC.5 SCL
#define   Sda        A4     // portC.4 SDA
#define   FcFerme    A3     // portC.3 bit 3 Fin de course fermé
#define   FcOuvert   A2     // portC.2 bit 2 Fin de course ouvert
#define   radiorelR  A1     // portC.1 bit 1 Radio2 par relais
#define   radiorelL  A0     // portC.0 bit 0 Radio1 par relais

// sélection de A6 et A7 du convertisseur analogique - 10 bits valeurs de 0 à 1023.
#define   LIS         6     // A6 image courant L
#define   RIS         7     // A7 image courant H

// vitesses lente et rapide (maxi 255)
#define   lent      150
#define   rapide    255

volatile int  compsec,Compt10Sec,secondes,nombre,i,dist_decP,dist_dec;
volatile int  Temps_boutonM,Temps_boutonP,val_tempo,ligne_menu,intensite,intensite_max ;
volatile int  Temps_boutonE,AncErreur,Seq,Temps_boutonEch,pos_ferme,Nbip;
volatile int  Tempo_menu,derniere_ligne,premiere_ligne,PageMenu,cpt_mvt,timer;
volatile int  tempo_affT,Temps_bornier,Tps_fonctionnement,Tps_fonc_P;
volatile int  decale,offset,cpt_mvt_10,courantRIS,courantLIS,s_consigne,courantLIS_arr,courantRIS_arr;
volatile int  Tps_accP,Tps_acc,Tps_dec,Tps_decP,pos,consigne,cons_loc,increment,anc_consigne;
volatile int  tempo_bip,nombre_bip,Max_bip,compt_seq,ADC_p,tps_marche,msg_fdc,tempo_apres_acc;
         int  _intensite_max,autorepeat,delayautorepeat; 
volatile byte Sens_Ouv,Sens_Ouv_P,PPS,PPS_P;
volatile byte bip,HauteurBuz,erreur;
volatile bool demande_arret,Fc_ferme,Fc_ouvert,avance,recul,debug ; 
volatile bool Aferme,Aouvert,simu,recul_cours,avance_cours,MemRecul,MemAvance ;
volatile bool dem_inc_boutonM,dem_inc_boutonP,Cellule_ok,ACellule,menu,Anc_BpP,Anc_BpM,Anc_BpE ;
volatile bool simuMenu,Simu8,Simu2,Enter,Anc_BpEch,Etat_BpP,Etat_BpM,Msg_cell_ok;
volatile bool dem_inc_boutonE,Etat_BpE,Etat_BpEch,curseur,decel,accel;
volatile bool Fm_M,Fm_E,Fm_P,Fm_Ech,dem_inc_boutonEch,Fm_O,Fm_F,Fd_O,Fd_F;
volatile bool arrete,Cde_bornier,Fm_Bornier,Abornier,demande_arr_imm;
volatile bool demande_recul_imm,FmBornier,Man_Bornier,litRIS,radioR,radioL,dem_aff_pos;
volatile bool Msg_cell_nok,trajet_long,Anc_Fus,Etat_Fus,marche_buz,AncR,AncL,FaireApprend;
volatile long iteration,poslong,tps_erreur;
char          inByte ;
String        s,chaine,vide,chaineEnCours; 

SSD1306AsciiWire oled;

// interruption timer toutes les 217,01388 micro secondes (2,017 ms) (460 Hz)
// compteur à 460  = génère 1 seconde
void Interrupt_T1() 
{
  Anc_Fus=Etat_Fus;
  Etat_Fus=digitalRead(Fuse);         // fusible ok à 0
  
  //if (!Etat_Fus) // si le fusible est ok, on tient compte des Fdc et de la cellule
  {
    Aferme=Fc_ferme;
    Aouvert=Fc_ouvert;
    ACellule=Cellule_ok;
    
    Fc_ferme=digitalRead(FcFerme);      // les Fdc ouvert et fermé doivent être électriquement à 1 au repos.
    Fc_ouvert=digitalRead(FcOuvert);    //  
    Cellule_ok=!digitalRead(Cellule);   // LOW=Cellule ok donc on inverse

    // fronts montants des Fdc (acostage)
    Fm_F=(!Aferme) & Fc_ferme;
    Fm_O=(!Aouvert) & Fc_ouvert;

    if (!ACellule & Cellule_ok) Msg_cell_ok=HIGH;
    if (ACellule & !Cellule_ok) Msg_cell_nok=HIGH;  
  }
  
  if ((!Anc_Fus) & (Etat_Fus)) erreur=3;
  if ((Anc_Fus) & (!Etat_Fus)) erreur=0;
 
  
  // Fronts descendants des Fdc (on les quitte)
  Fd_F=Aferme & (!Fc_ferme);
  Fd_O=Aouvert & (!Fc_ouvert); 

  // acostage du fdc fermé : mémoriser la position si on a démarré depuis le fdc_recul sans arret
  if (Fm_F & avance) // & trajet_long)
  {
    trajet_long=LOW;
    pos_ferme=pos;
    //proc_arret_immediat();
    //Serial.println(pos_ferme);
  }

  if (marche_buz)
  {
    digitalWrite(buzzer,bitRead(bip,HauteurBuz));   // HauteurBuz=bit de 0 à 3 pour la hauteur de la note
    ++bip; // compteur de 0 à 15
    if (bip==16) bip=0;
  }
  else digitalWrite(buzzer,LOW);
 
  ++Compt10Sec;    // compteur 1/10eme de seconde

  // compteurs appui boutons (en temps timer 217µs)
  if ((dem_inc_boutonM) & (Temps_boutonM<32000)) ++Temps_boutonM;
  if ((dem_inc_boutonP) & (Temps_boutonP<32000)) ++Temps_boutonP;
  if ((dem_inc_boutonE) & (Temps_boutonE<32000)) ++Temps_boutonE;
  if ((dem_inc_boutonEch) & (Temps_boutonEch<32000)) ++Temps_boutonEch;

  // séquenceur 1/10 seconde---------------
  if (Compt10Sec>=460)
  {
    Compt10Sec=0;
    ++compsec;       // compteur 1 seconde
    if (avance_cours | recul_cours) ++cpt_mvt_10; else cpt_mvt_10=0;  // compteur mvt en 1/10 de s
        
    if (val_tempo!=0) --val_tempo;
    if (tempo_bip!=0) ++tempo_bip;
    if (tempo_apres_acc!=0) {++tempo_apres_acc;}
    if (tempo_apres_acc>10) tempo_apres_acc=0;
    
    if (nombre_bip<Max_bip)
    {
      if (tempo_bip==0)
      {
        tempo_bip=1;
      }
      if (tempo_bip==5) 
      {
        marche_buz=HIGH;
      }
      if (tempo_bip==10)
      {
        if (marche_buz) ++nombre_bip;
        tempo_bip=1;
        marche_buz=LOW;
      } 
    }

    if (tempo_bip>10) tempo_bip=0;
    if (erreur==0) {tempo_bip=0;marche_buz=LOW;}
    
    // on recommence un cycle buzzer au bout de 8s
    if (compt_seq==8)
    {
      compt_seq=1;  // séquenceur buzzer à 10s (cycle complet)
      tempo_bip=1;
      nombre_bip=0;
    }
    
    // seconde------------------
    if (compsec>=10)
    {
      ++compt_seq;  // séquenceur buzzer
      
      compsec=0;
      ++secondes;

      if (tps_erreur!=0) tps_erreur++;
      // arreter le buzzer au bout d'une heure
      if (tps_erreur>3600) 
      {
        Max_bip=0;
      }
      if (tempo_affT!=0) --tempo_affT;
      if (avance_cours | recul_cours) ++cpt_mvt;
      if (Tempo_menu>0) {++Tempo_menu;} 
      if (tps_marche>0) ++tps_marche;
      if (tps_marche==30) {digitalWrite(infomarche,LOW);tps_marche=0;}
    } 

    // intégration position: la distance est la vitesse (cons_loc) mesuré tous les 1/10ème de s  ------------------
    if (avance_cours)
    {
      poslong=poslong+cons_loc;   // longint
      pos=poslong/10;
    }
    if (recul_cours)
    {
      poslong=poslong-cons_loc;  // longint
      pos=poslong/10;
    }
  }
  
  // filtrage commande---------------------------------------------------------
  Abornier=Cde_bornier;
  if ((digitalRead(Commande))==LOW) {Temps_bornier=60;Cde_bornier=HIGH;}
  if (Temps_bornier>0) 
  {
    --Temps_bornier;
    if (Temps_bornier==0) {Cde_bornier=LOW;}
  }
  Fm_Bornier=!Abornier & Cde_bornier;
  if (Fm_Bornier) Man_Bornier=!menu;

  // raz de la position si FDC ouvert (origine)
  if (Fc_ouvert) {pos=0;poslong=0;}
  
  // lecture courant pont L et R (LIS et RIS) ---------------------------------
  if (bit_is_clear(ADCSRA,ADSC))  // échantillon prêt ?
  {  
    // lire la valeur analogique ; elle peut être faible ...
    ADC_p=ADC; 
    if (litRIS) 
    {
      courantRIS=ADC_p;  
      if (arrete) courantRIS_arr=ADC_p;  // courant RIS à l'arret (offset)
    }
    else 
    {
      courantLIS=ADC_p ;  
      if (arrete) courantLIS_arr=ADC_p;  // courant LIS à l'arret (offset)
    }
   
    if ( ((avance_cours) & (Sens_Ouv==1)) | ((recul_cours) & (Sens_Ouv==0)) )  
    {  
      intensite=courantLIS-courantLIS_arr;
    }  
    if ( ((recul_cours)  & (Sens_Ouv==1)) | ((avance_cours) & (Sens_Ouv==0)) )
    {
      intensite=courantRIS-courantRIS_arr;
    
    }
    // on ne vérifie pas l'intensité en accélération ou en décélération car elle crée un pic
    if ((avance_cours | recul_cours) & (!accel) & (!decel) & (tempo_apres_acc==0) )
    { 
      if (intensite>255L*intensite_max/consigne)  // la consigne max sert de comparaison de courant. "L" obligatoire car on travaille en entier long.
      {
        if (avance_cours) erreur=1; else erreur=2;
        if (debug) Serial.print(intensite);Serial.print(" / ");Serial.println(255L*intensite_max/consigne);
        demande_arr_imm=HIGH;
      }
    }  
   
    litRIS=!litRIS;
    
    // demande de conversion analogique suivante
    if (litRIS) ADMUX=(0xf0 & ADMUX) | RIS ;     // A7 au multiplexeur 
    else        ADMUX=(0xf0 & ADMUX) | LIS ;     // A6 
    ADCSRA |=(1 << ADSC);            // mise à 1 du bit ADSC du registre ADCSRA (demande de conversion)   
  }
} 

// masque de l'écran de base
void Ecran_base()
{
  oled.setInvertMode(0);
  oled.setFont(System5x7);
  oled.clear();
  oled.set2X();
  oled.println(F("Portail FS")); 
  oled.set1X();
  //oled.setScrollMode(SCROLL_MODE_AUTO);
  oled.setScrollMode(SCROLL_MODE_OFF);
  oled.setCursor(0,ligne_pos);oled.print(F("Pos=0"));
  oled.setCursor(0,7);oled.print(F("Intensite MAX="));oled.println(intensite_max);
}

void ecrit_eprom()
{
  EEPROM.write(0,Sens_Ouv); 
  EEPROM.write(1,PPS); 

  EEPROM.write(3,Tps_fonctionnement);
  EEPROM.write(4,dist_dec >> 8);    // 2 octets
  EEPROM.write(5,dist_dec & 0xFF);   
  EEPROM.write(6,Tps_acc);
  EEPROM.write(7,Tps_dec);
  EEPROM.write(8,intensite_max >>8);
  EEPROM.write(9,intensite_max & 0xFF); 
  EEPROM.write(10,pos_ferme >>8);
  EEPROM.write(11,pos_ferme & 0xFF); 
}

void lit_eprom()
{
   Sens_Ouv=EEPROM.read(0);           // sens de l'ouverture
   PPS=EEPROM.read(1);                // mode de fonctionnement : Avance / Arret / Recul  (sinon Avance / Recul) 
   Tps_fonctionnement=EEPROM.read(3); // temps maximal de fonctionnement
   dist_dec=EEPROM.read(4)*256+EEPROM.read(5);    // paramètre sur 2 octets (int) au moins 500
   Tps_acc=EEPROM.read(6);           
   Tps_dec=EEPROM.read(7);
   intensite_max=EEPROM.read(8)*256+EEPROM.read(9);
   pos_ferme=EEPROM.read(10)*256+EEPROM.read(11);
   // intensite_max=1500;  // &&
   
   if ((Sens_Ouv>1) | (Sens_Ouv<0)) Sens_Ouv=1;
   if ((PPS>1) | (PPS<0)) PPS=1;
   if ((Tps_fonctionnement>99) | (Tps_fonctionnement<1)) Tps_fonctionnement=99;
   if ((dist_dec>3000) | (dist_dec<500)) dist_dec=500;  
  
   if ((Tps_acc>30) | (Tps_acc<2)) Tps_acc=10;
   if ((Tps_dec>30) | (Tps_dec<2)) Tps_dec=10;

   if (intensite_max<=0) intensite_max=500;
        
   Serial.print(F("Sens ouverture="));Serial.println(Sens_Ouv);
   Serial.print(F("Sequentiel="));Serial.println(PPS);
   Serial.print(F("Tps fonctionnement maxi="));Serial.println(Tps_fonctionnement); 
   Serial.print(F("Distance ralenti="));Serial.println(dist_dec);
   Serial.print(F("Tps acc="));Serial.println(Tps_acc);
   Serial.print(F("Tps dec="));Serial.println(Tps_dec);
   Serial.print(F("Courant Max="));Serial.println(intensite_max);
   Serial.print(F("Position Fdc ferme="));Serial.println(pos_ferme);
}
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
void loop() 
{
  traitement();    // traitement de fond 
  if (debug)
  {  
    if (((avance_cours | recul_cours)) & (intensite!=0)) 
    {
      if (consigne==lent) Serial.print("L "); else Serial.print("R ");
      Serial.println(intensite);
    }
  }  
  
  if (!menu)
  { 
    // affichage erreur
    if ( (AncErreur==0) & ((erreur==1) | (erreur==2)) )
    { 
      AncErreur=erreur;
      s=F("Courant moteur elevé");
      Max_bip=erreur;
      tps_erreur=1;
      Serial.println(s);
      oled.setCursor(0,ligne_erreur);oled.print(s);
      oled.print(vide);

      if (erreur==1) {consigne=lent;proc_recul();}
    }

    /*
    if ((AncErreur==1) & (erreur==0))
    { 
      AncErreur=erreur;
      oled.setCursor(0,ligne_erreur);oled.print(vide);
    }
    */

    if ((AncErreur==0) & (erreur==4))
    { 
      AncErreur=erreur;
      s=F("Erreur mvt trop long");
      tps_erreur=1;
      Max_bip=4;
      oled.setCursor(0,ligne_erreur);oled.print(s);
      oled.print(vide);
      Serial.println(s);
    }  

    if ((AncErreur==0) & (erreur==3))
    { 
      AncErreur=erreur;
      Max_bip=3; 
      tps_erreur=1;
      
      arret();
      s=F("Fusible F1 HS");
      oled.setCursor(0,ligne_erreur);oled.print(s);
      oled.print(vide);
      Serial.println(s);   
    }  

    if ((AncErreur!=0) & (erreur==0))
    { 
      AncErreur=erreur;
      Max_bip=0;
      //oled.setCursor(0,ligne_erreur);oled.print(vide);
      Ecran_base();
    }
    
   
    // Affichage Evt Fdc et cellule ----------------------------------------------------------
    if ((Fc_ferme) & (Fc_ouvert) & (msg_fdc!=1)) 
    {
      s=F("Fdc ouvert et ferme ");
      msg_fdc=1;
      Serial.println(s);
      oled.setCursor(0,4);oled.print(s);
    }
    
    if ((Fc_ferme) & (!Fc_ouvert) & (msg_fdc!=2)) 
    {
      s=F("Fdc ferme           ");
      msg_fdc=2;
      Serial.println(s);
      oled.setCursor(0,4);oled.print(s);
    }
    if ((!Fc_ferme) & (!Fc_ouvert) & (msg_fdc!=3))
    {
      Serial.println(F("Fdc ferme libéré "));
      msg_fdc=3;
      oled.setCursor(0,4);oled.print(vide);
    }
    
    if ((Fc_ouvert) & (!Fc_ferme) & (msg_fdc!=4)) 
    {
      msg_fdc=4;
      s=F("Fdc ouvert           ");
      Serial.println(s);
      oled.setCursor(0,4);oled.print(s);
    }
   

    if (Msg_cell_ok)
    {
      Msg_cell_ok=LOW;
      s=F("Cellule OK");
      Serial.println(s);
      oled.setCursor(0,6);oled.print(s);oled.print(vide);
    } 

    if (Msg_cell_nok)
    {
      Msg_cell_nok=LOW;
      s=F("Cellule occultee");
      Serial.println(s);
      oled.setCursor(0,6);oled.println(s);
    }
  }
  
  //réception des données depuis USB
  nombre=Serial.available() ; // nombre de caractères disponibles sur la liaison série
  if (nombre>0)
  {
    //Serial.println(nombre);
    for (i=0 ; i<nombre ; i++)
    {
      inByte = Serial.read();
      //Serial.print(inByte);
      //if (inByte==13) Serial.print("CR");
      //if (inByte==10) Serial.print("LF");
      if ((inByte!=13) & (inByte!=10)) chaineEnCours=chaineEnCours+inByte;
      if (inByte==13)
      {  
        //Serial.println("CR");Serial.println(chaineEnCours);
        if (menu) Tempo_menu=1;
        chaine=chaineEnCours;
        if (chaine=="") {demande_arret=!menu;Enter=HIGH;chaine="";}  // pas de demande d'arret en mode menu
        //Serial.println();
        //Serial.print("chaine=");Serial.println(chaine);
        chaineEnCours=""; 
      }
    }
  }    
  
  if (chaine=="?") 
  {
    Serial.println(F("pos     : Affiche la position"));
    Serial.println(F("cour    : Affiche les courants"));
    Serial.println(F("tar     : Avance en rapide")); 
    tempo(1);
    Serial.println(F("trr     : Recul en rapide\r\ntal     : Avance en lent\r\ntrl     : Recul en lent")); 
    tempo(1);  
    Serial.println(F("ENTREE  : Arret")); 
    Serial.println(F("e       : Etat des entrees"));   
    tempo(1);  
    Serial.println(F("simu    : Simu commande bornier"));
    Serial.println(F("menu    : Mode menu (touches 8/2 = < >)"));
    Serial.println(F("im      : Infos menu"));
    Serial.println(F("apprend : lance l'apprentissage"));
    chaine="";
  }
  else

  if (chaine==F("pos"))
  {
    Serial.print(F("Pos=")); Serial.println(pos);
    Serial.print(F("Pos ferme=")); Serial.println(pos_ferme);
    chaine="";
  }
  else

  if (chaine==F("cour"))
  {
    Serial.print(F("Courant R="));Serial.println(courantRIS);
    Serial.print(F("Courant L="));Serial.println(courantLIS);
    Serial.print(F("Courant arret L="));Serial.println(courantLIS_arr);
    Serial.print(F("Courant arret R="));Serial.println(courantRIS_arr);  
    chaine="";
  }
  else
  
  if (chaine==F("menu"))
  {
    simuMenu=HIGH;
    Serial.println(F("Mode MENU"));
    chaine="";
  }
  else

  if (chaine==F("8"))
  {
    Simu8=HIGH;
    chaine="";
    Tempo_menu=1;
  }
  else

  if (chaine==F("2"))
  {
    Simu2=HIGH;
    chaine="";
    Tempo_menu=1;
  }
  else
  
  if (chaine==F("simu"))
  {
    simu=HIGH;
    chaine="";
  }
  else

  if (chaine.substring(0,3)=="e")
  {
    Serial.print(F("Fc Ferme   ")); Serial.print(digitalRead(FcFerme));Serial.print("  ");Serial.println(Fc_ferme);
    Serial.print(F("Fc Ouvert  ")); Serial.print(digitalRead(FcOuvert));Serial.print("  ");Serial.println(Fc_ouvert);
    tempo(1);
    Serial.print(F("Cellule    ")); Serial.println(digitalRead(Cellule));
    Serial.print(F("Commande   ")); Serial.println(digitalRead(Commande));
    Serial.print(F("Bouton ECH ")); Serial.println(digitalRead(BpEch));
    tempo(1);
    Serial.print(F("Bouton E   ")); Serial.println(digitalRead(BpE));
    Serial.print(F("Bouton +   ")); Serial.println(digitalRead(BpP));
    Serial.print(F("Bouton -   ")); Serial.println(digitalRead(BpM));   
    chaine="";
  }
  else
  
  if (chaine==F("apprend"))
  {  
    menu=HIGH;
    FaireApprend=HIGH;
    chaine="";
  }
  else
    
  // avance rapide
  if (chaine==F("tar"))
  {  
    consigne=rapide;
    proc_avance();
    chaine="";
  }
  else

  // recul rapide
  if (chaine==F("trr"))
  {
    consigne=rapide;
    proc_recul();
    chaine="";
  }
  else

  // avance lente
  if (chaine==F("tal"))
  {
    consigne=lent;
    proc_avance();
    chaine="";
  }
  else

  // recul lent
  if (chaine==F("trl"))
  {
    consigne=lent;
    proc_recul();
    chaine="";
  }
  else
  
  if (chaine==F("im"))
  {
    Serial.print(F("Menu="));Serial.println(menu);
    Serial.print(F("ligne menu="));Serial.println(ligne_menu);
    Serial.print(F("Page="));Serial.println(PageMenu);
    Serial.print(F("Curseur="));Serial.println(curseur); 
    chaine="";
  }

  else
  if (chaine!="")
  {
   Serial.print(F("Commande inconnue:"));Serial.println(chaine);
   chaine="";
  }

  // demande de mouvement depuis le bornier (J4 bornes 2/7) ou radio -----------------------
  if (
      (
        Man_Bornier | 
        (!AncR & radioR) | 
        (!AncL & radioL)
      ) 
      & ((!menu & !Etat_Fus) | simu) 
     )  
   {  
    if (Man_Bornier) s=F("Commande bornier");
    if (radioL | radioR) s=F("Commande radio  ");
    Man_Bornier=LOW;
    simu=LOW;
    Serial.println(s);
    oled.setCursor(0,5);oled.println(s);
    if ((erreur==1) | (erreur==2)) erreur=0;
    
    // si arreté sur un FdC 
    if (Fc_ouvert | Fc_ferme)
    {
      if (!avance_cours & !recul_cours) 
      {
        Serial.println(F("cas1"));
        if (Fc_ouvert) {consigne=rapide;proc_avance();}
        if (Fc_ferme)  {consigne=rapide;proc_recul();}
      }  
      else 
        { if ((erreur==1) | (erreur==2)) erreur=0;
          Serial.println(F("cas2"));arret();}
    }  
    
    else
    {
      // si pas arrété sur un FdC et pas de mvt en cours
      if (!avance_cours & !recul_cours)
      {
        
        // si cellule occultée, on autorise que le recul en lent
        if (!Cellule_ok) {Serial.println(F("cas3.1"));consigne=lent;proc_recul();}
        else
        {
          // dernier mvt était recul ou avance?
          Serial.println(F("cas3.2"));
          if (recul) {consigne=rapide;proc_avance();} else {consigne=rapide;proc_recul();} 
        }  
      }
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
